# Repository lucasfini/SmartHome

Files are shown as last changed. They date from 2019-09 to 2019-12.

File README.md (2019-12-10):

# MQ-2 (Semiconductor Sensor for Combustible Gas)

## Table of Contents

* [Introduction](#Introduction)
* [Bill of Materials/Budget](#B)
* [Time Commitment](#T)
* [Mechanical Assembly](#M)
* [Pcb Soldering](#P)
* [Power Up](#PU)
* [Unit Testing](#UT)
* [Production Testing](#PT)
* [Reproducible?](#R)

## <a name="Introduction"> Introduction </a>

<p> The MQ-2 is a Metal Oxide Semiconductor that detects LPG, Smoke, Alcohol,Propane, Hydrogen, Methane and Carbon Monoxide. It does this by looking at change of resistence before and after a gas comes in contact with the material. These concentrations can range anywhere from 200 - 10,000ppm. The sensor is great for a multiple range of gas detection, and can be used in a ton of industrial, and at home areas. This Mq-2 sensor from Willwin is a very low-cost, and very responsive sensor. The operating voltage is 5v with it consuming <800mw of energy. It has very easy wiring, and works perfectly with the stm32 blue pill.<p>
 
## UML-Diagram

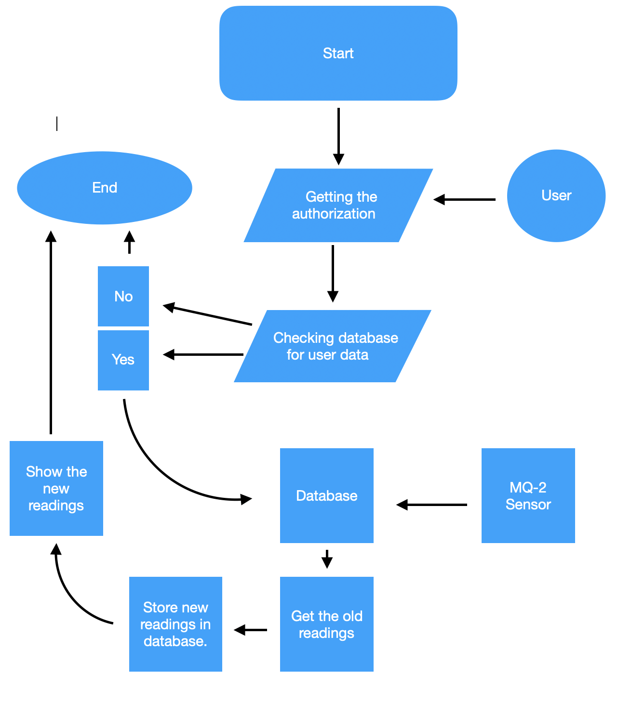
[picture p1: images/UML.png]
image of packages


System Diagram

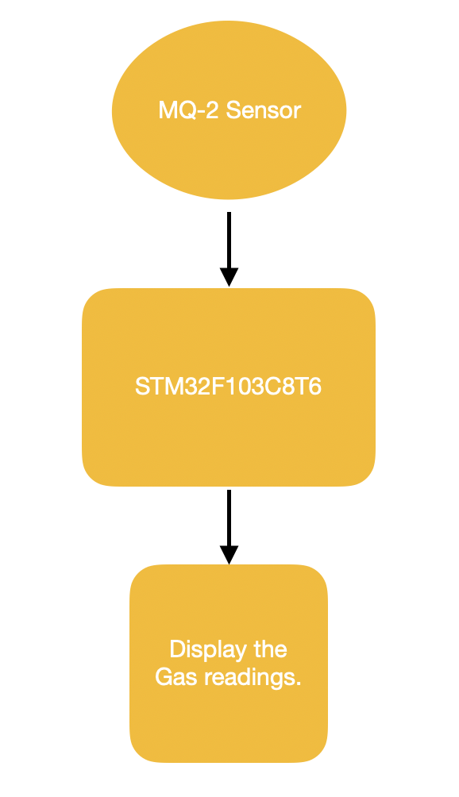
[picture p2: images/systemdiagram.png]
image of packages


## <a name="B"> Bill of Materials/Budget </a>

The required price for my whole project is about $100. This is the price if you are a student at humber, and have collected the parts kit at the beginning of semester 1. If you do not have the parts kit, you will need to pay an extra $120 dollars for the parts kit. I also used the schools prototype lab to get my case and pcb made. If you would like to go to a external dealer, the price will increase on top of the $220 already spent for the parts and the kit. If you are a student the required materials will be below for you to view. 

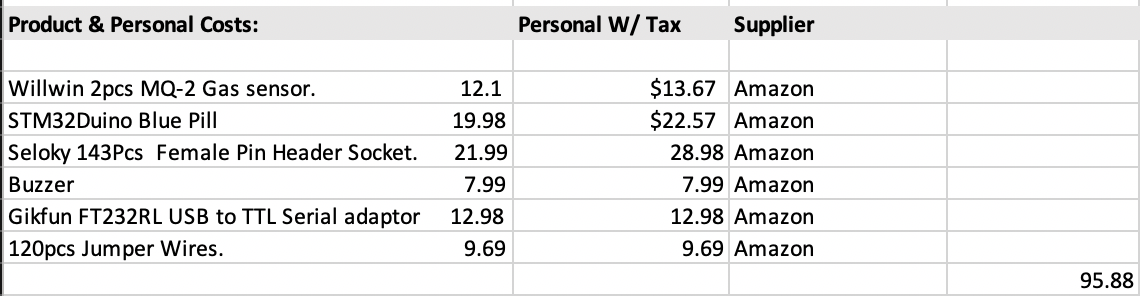
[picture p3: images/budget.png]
image of budget


## <a name="T"> Time Commitment </a>

The first time Commitment I will talk about is the CENG-317 schedule. You will get 14 weeks to complete this hardware assignment. Each week is a new task to do, some will take longer than others. The weeks that most people have difficulties on is week 9 and 11. These weeks are the PCB solder and Enclosure due dates. Since you need external equipment to do these two weeks, it will be more difficult to find the time to do them. Plus, if you design your enclosure or pcb wrong, you will need to keep on trying until you get them right. Note: Try to be ahead for these two weeks, just incase something unexpected happens. 

Now, this is for people that are building this on their free time. If you were to have all the equipment, and just needed to get the pcb and enclosure it should take you about a week, because of the shipping of pcb and enclosure. If you already have a pcb and enclosure you can realistically do this in a weekend. That is only if you have everything with you and are prepared. 

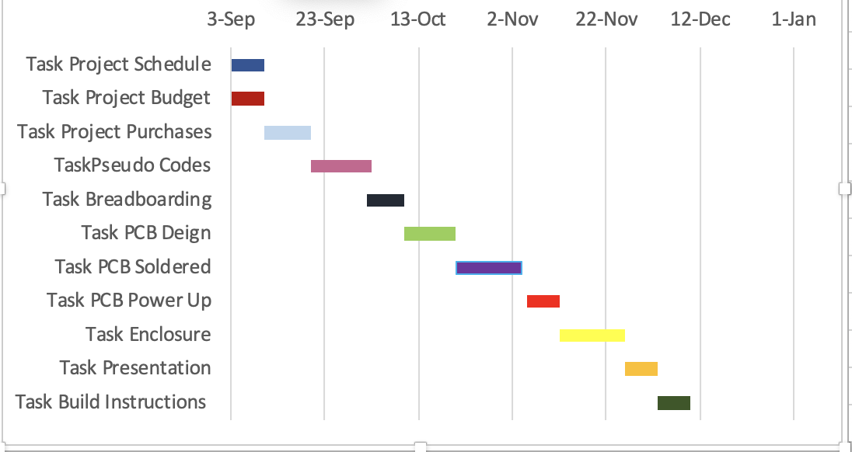
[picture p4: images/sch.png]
image of schedule


## <a name="M"> Mechanical Assembly </a>

Wanna learn how to probably setup,code,wire,and enclose?  **Instructions Below**
Side Note: Before starting please make sure you have the materials listed above, in the budget section. 

1. Install [Arduino](https://www.arduino.cc/en/main/software)
2. To learn how to program the STM32 Bluepill we will start with a simple blink program. First we need to install some board managers. Go to Tools>Boards Manager and install STM32F4xx boards and STM32F1xx/GD32F1xx baords.

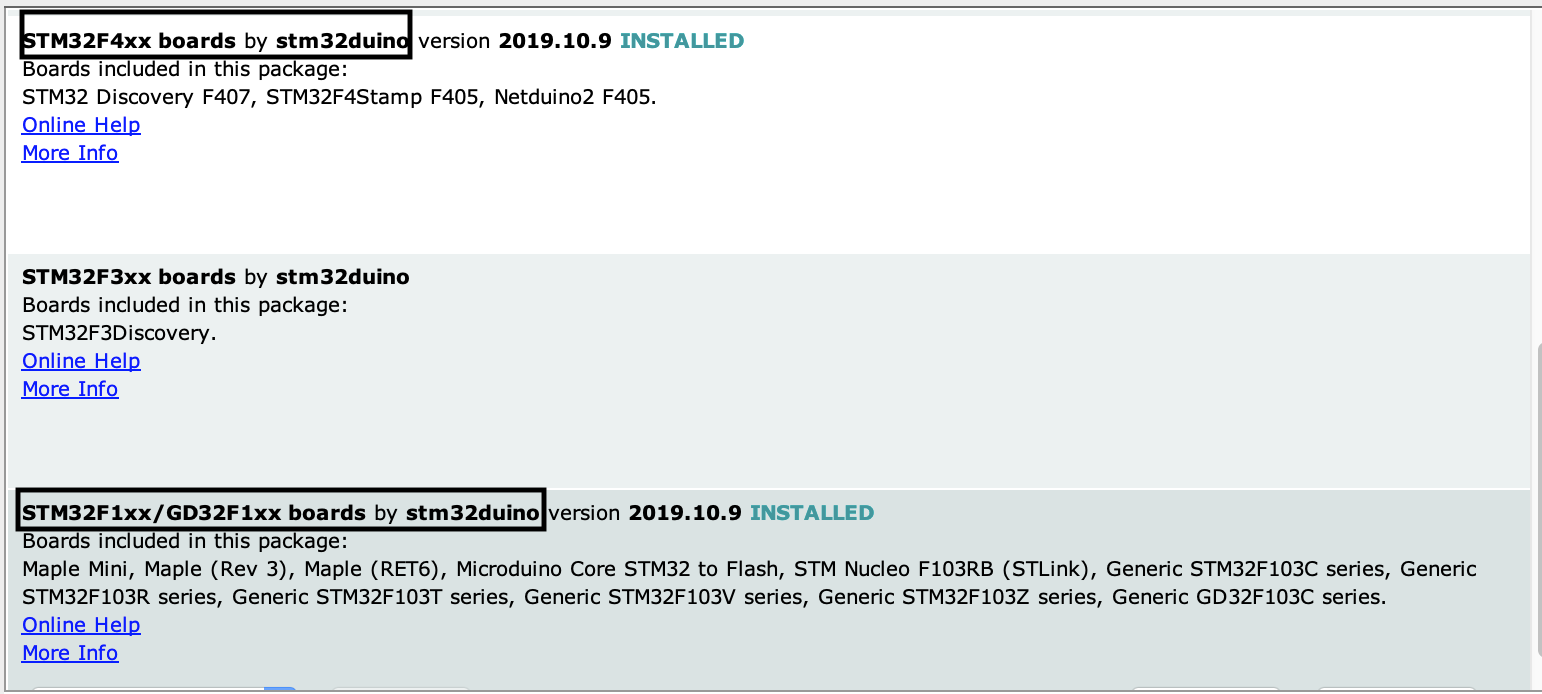
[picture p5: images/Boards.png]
image of baord


3. Next go to Files>Examples>Basics>Blink. Change the code to how it is below.

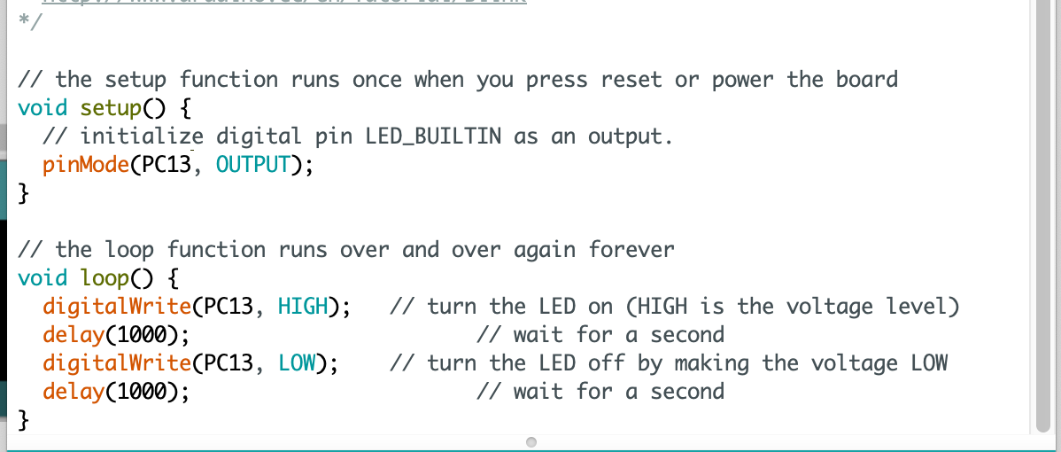
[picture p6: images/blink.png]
image of blinkcode


4.Now you will need to setup the device on your breadboard. Make sure to switch the BOOT0 on the blue pill from 0 to 1. This will put it in programming mode. The picture below will show you how to do it. Once done plug the FTDI programmer into your computer.

Pin Layout:

<p>Programmer to stm32<p>
<p>gnd to G<p>
<p>vcc to 5v<p>
<p>tx to a10<p>
<p>rx to a9<p>

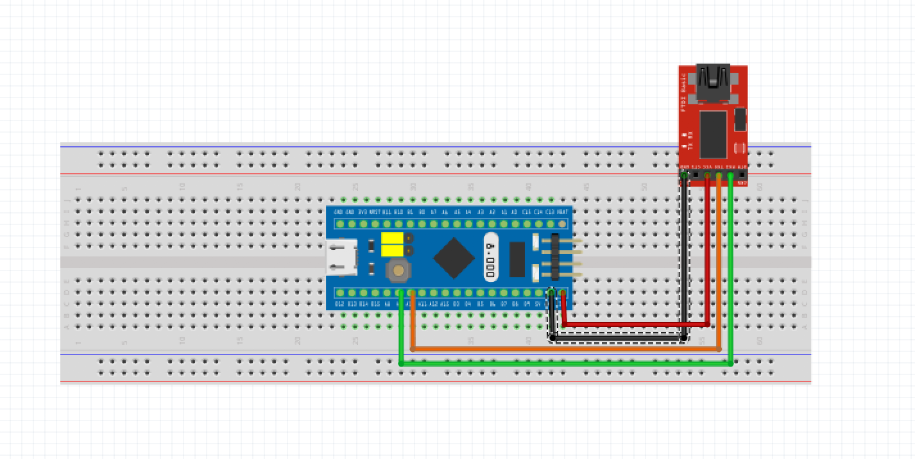
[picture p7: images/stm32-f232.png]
image of breadboard


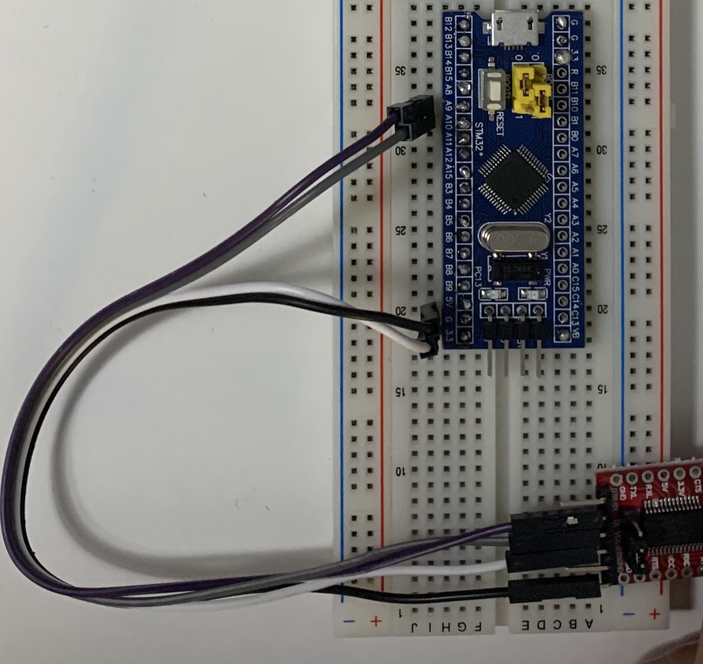
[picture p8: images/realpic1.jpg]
image of breadboard


5. Now go to tools and make sure to have similar options that are in the picture below. 

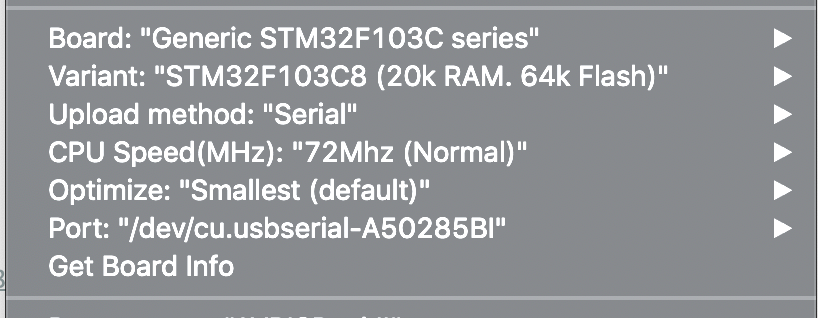
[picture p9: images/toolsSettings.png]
image of breadboard


6. Now once everthing is done, Click upload on the top left of arduino. It should show it compiling and once it is done, there should be a green light that will blink on the STM32. If there is an issue try hitting the reset button on the STM32 and try uploading again. 

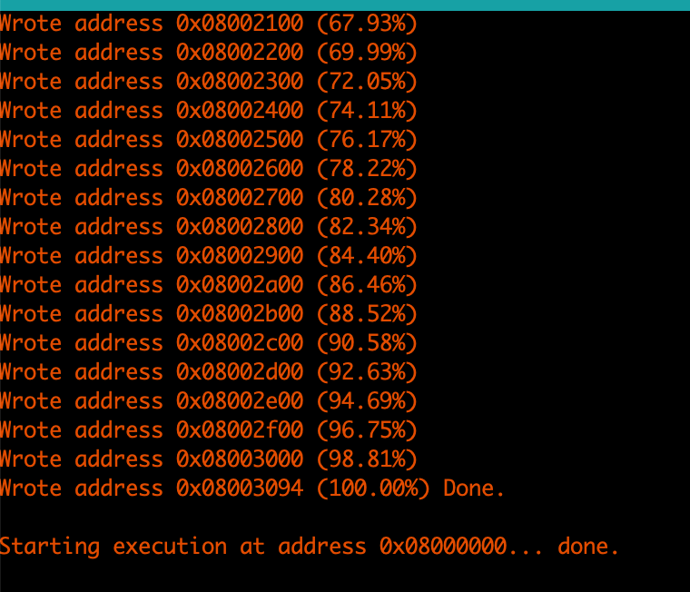
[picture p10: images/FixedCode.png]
image of compile.


7. Now that all that is done with we can continue with attaching the buzzer, and MQ-2 Gas sensor.
The New Connections will be:

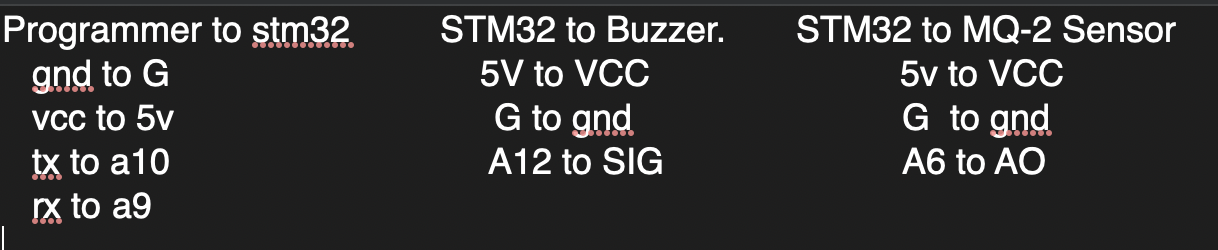
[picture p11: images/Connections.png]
image of completed connections


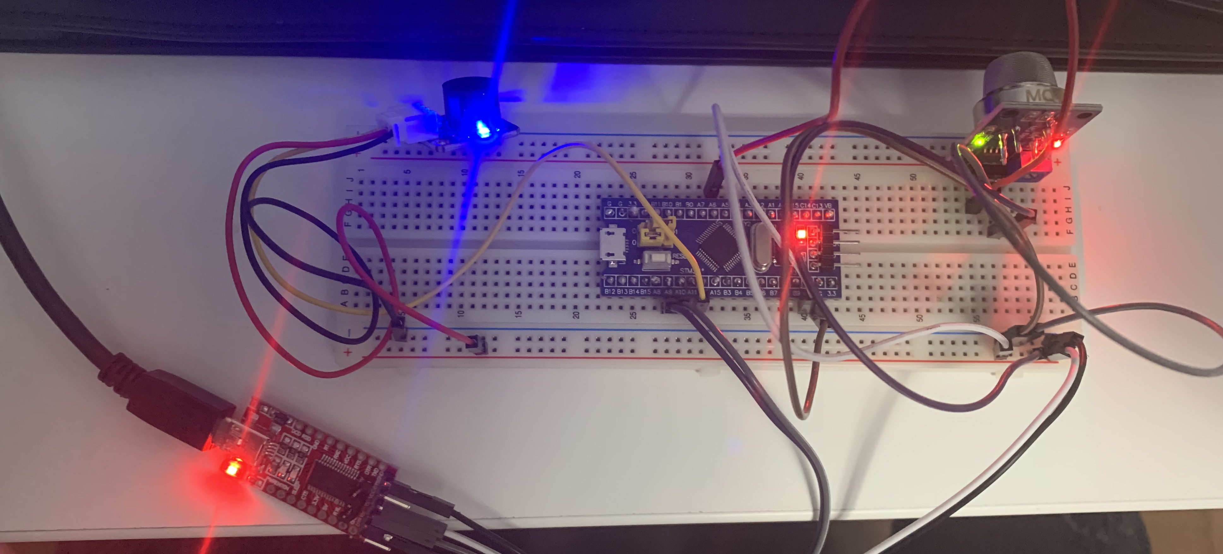
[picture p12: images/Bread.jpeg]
image of completed breadbaord.


## <a name="P"> Pcb and Soldering </a>

Now that we have the breadboarding portion completed, lets move on to PCB completion. I did have some difficulty making the PCB and had to remake my PCB 3 times to get it working perfectly. Note: When imported a part from the internet to fritzing, even though it says it might be the part you need make sure its the right dimentions. This happened to me with my STM32,and I had to remake the PCB board. Another note: If you can't find the right parts online or in their internal library, use a **Generic female Header**. It can be used in place of most parts. After designing the PCB you should send the gerber files to the prototype lab so that they can make your PCB. Takes 1-2 days, depending on time and demand. The solder wasn't to difficult, just make sure you take your time, and make sure no two connections aren't soldered together. 

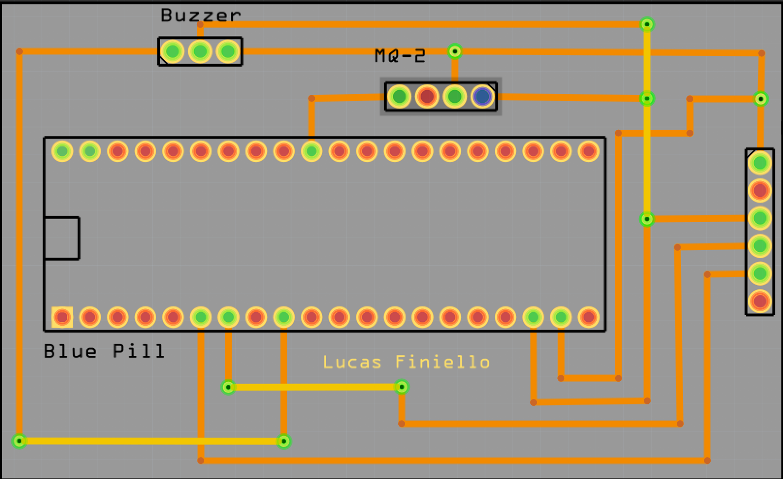
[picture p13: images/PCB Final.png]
Image of Pcb
  
  
 Bottom of the PCB board. I wanted everything on the top, so I made sure to put on the wire on the bottom. Since all the wiring is on the bottom, that means most of the soldering is on the bottom. 
 
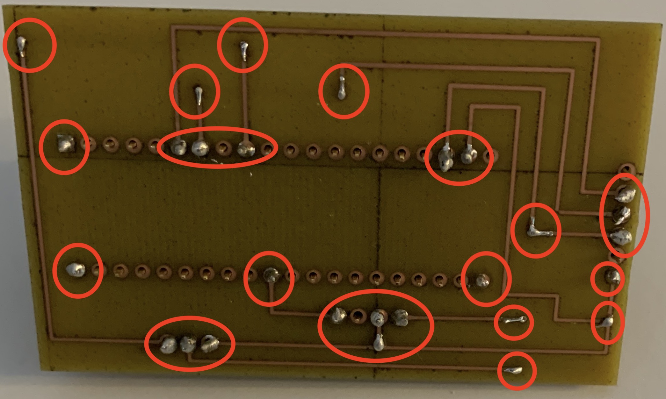
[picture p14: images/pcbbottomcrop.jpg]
Image of Pcb
  
   
 Top of PCB board. This is where my STM32, MQ-2 Sensor, Buzzor and FTDI programmer will plug in. 
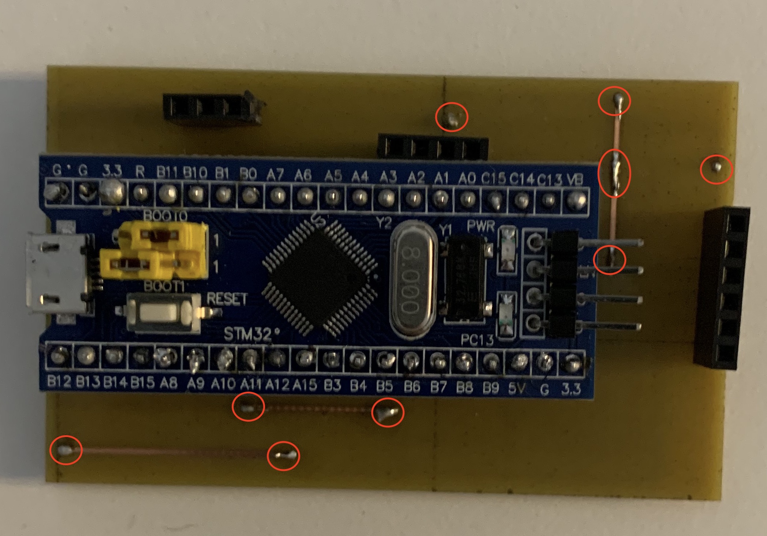
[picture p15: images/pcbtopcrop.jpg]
Image of Pcb
  
      
 How the PCB looks when it is plugged in and all the components are working.
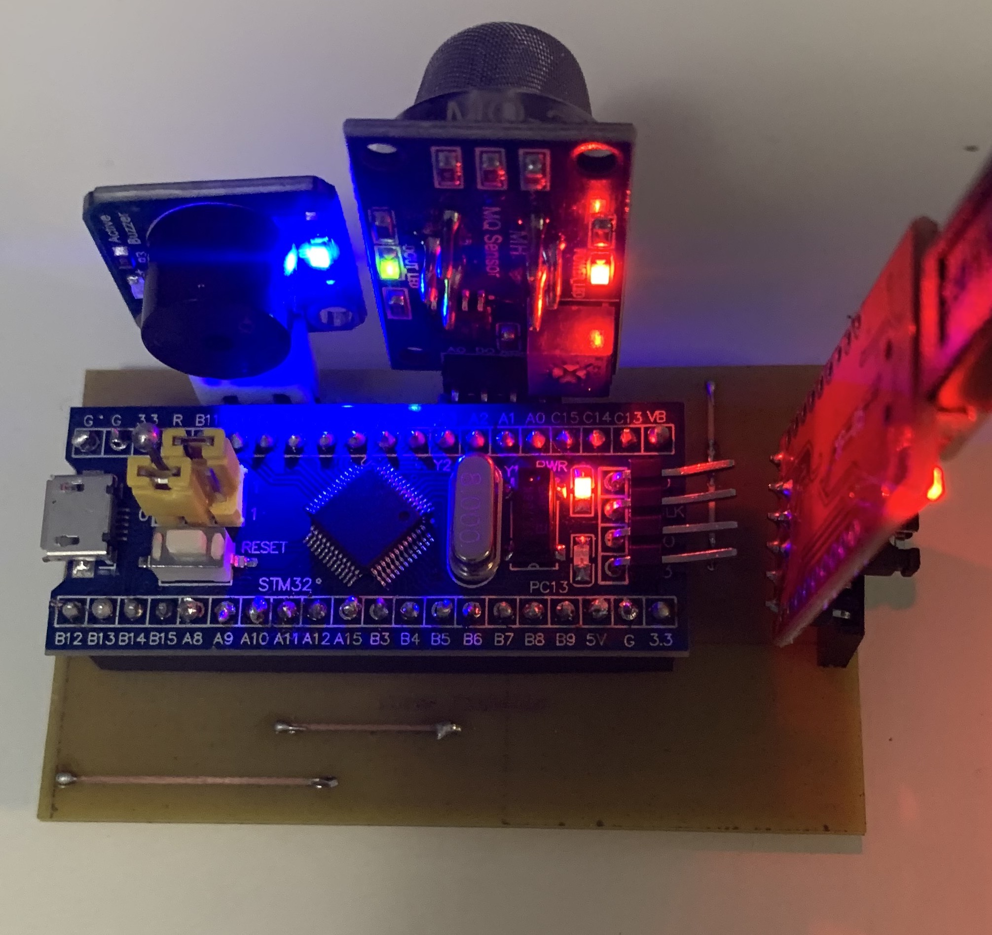
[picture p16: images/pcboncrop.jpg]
Image of Pcb
  

## <a name="PU"> Power Up</a>

Before plugging anything in you want to look at your PCB board and make sure all the wiring goes to the right place, and all the soldering is done correctly. Once plugged in make sure that everything lights up and that nothing is out. If something isn't lit, try fidgeting with the component that isn't turned on. If it still isn't on look at your soldering and make sure all the vias and connections are soldered correctly. If it still isn't working go back to your PCB design and make sure all the connections are correct, and if that doesn't work then you might have a faulty component. 

 How the PCB looks when it is plugged in and all the components are working.
  Image of Pcb

## <a name="UT"> Unit Testing </a>
I tested my product using a lighter. Since lighters contain butane the sensor should be able to sense the gas. As you can see below whenever I activate the lighter, the senser will senses a gas, and once it reaches above a safe thresh hold, the buzzer turns on. Once the thresh hold goes back down below 1100, it is safe and the buzzer turns off. With this sensor you will wanna configure it and make sure it is running properly. You also do need to allow it some time to heat up before use, or else the value might be higher than usual.

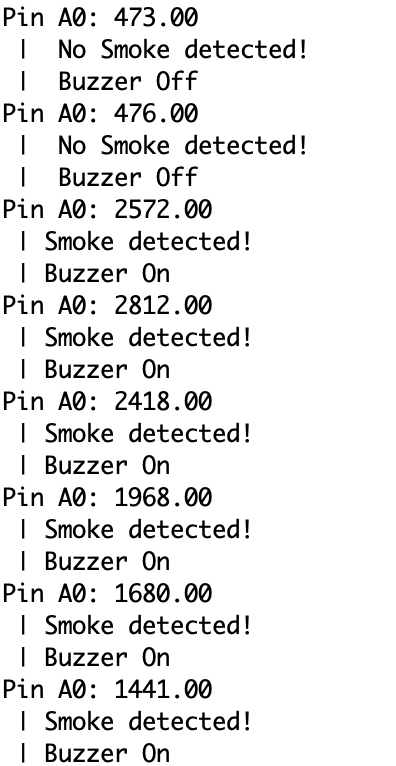
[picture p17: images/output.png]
Image of output

  
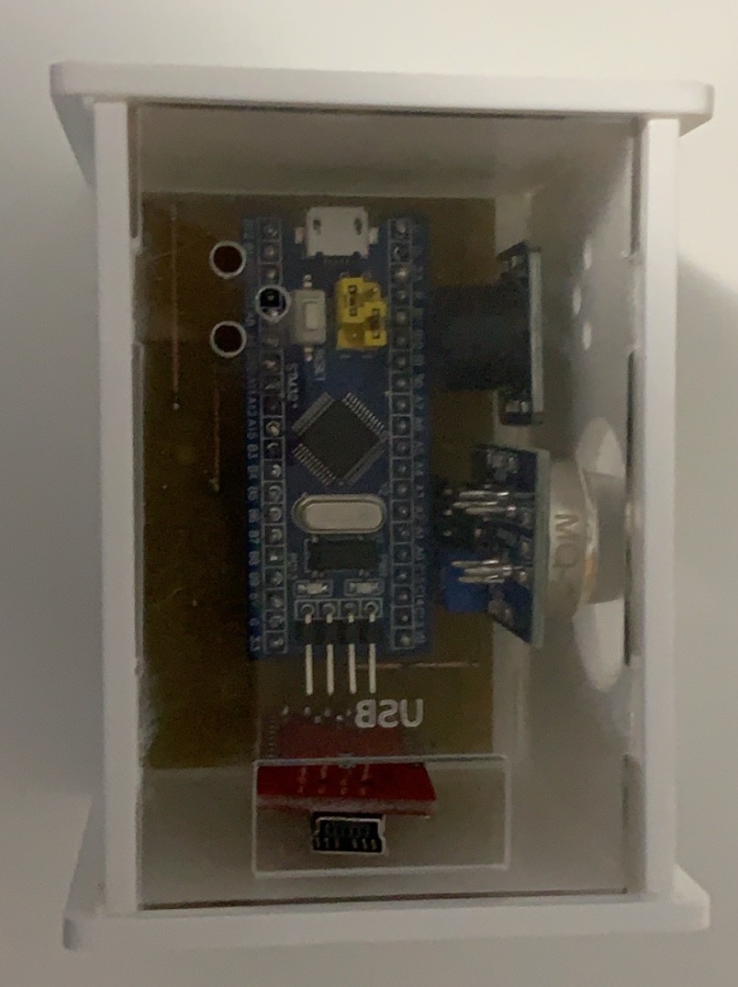
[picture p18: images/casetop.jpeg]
Image of casetop

  
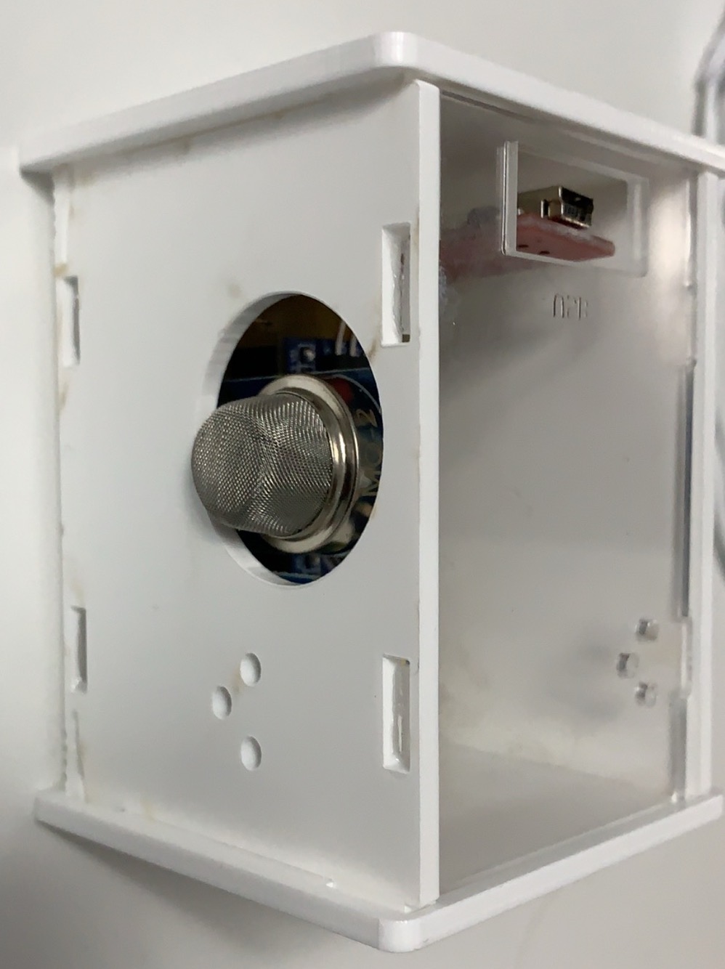
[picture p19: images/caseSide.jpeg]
Image of caseside


## <a name="PT"> Production Testing </a>

With this product I only was able to test one gas, and the only reason for that is because all the other gasses are very dangerous, and hard to get a hold of. I was able to monitor the products data, and make sure everything was running correctly. If I was manufacturing multiple units of this product I would first make sure all soldering was done by automated machinary. It would speed up production time, and efficiency. Secondly, if this is used as a smoke sensor I would hard solder all the components to the PCB. I would do this because it would firstly, be more secure and secondly, users wouldn't have to worry about components coming loose. 

## <a name="R"> Reproducible?  </a>

I believe that by following my instructions the product is reproducible. The only thing I didn't include was the Arduino code for testing out the sensor and that is because I don't want future students fully copying this github.

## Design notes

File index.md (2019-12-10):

 <h1> Smart Home Monitor - Lucas, Andrew, Luca </h1>
 
 <h1 id="november-26th-week-12">November 26th, 2019 (Week 12)</h1>
 
 <p> Finished my powerpoint presentation and my casing. I am all ready to present and have completed everything in the class except the ReadME file.<p>
 
 Image of case top
 
 Image of case side
 
 <h1 id="november-19th-week-11">November 19th, 2019 (Week 11)</h1>
 <p> I have designed the case on coral Draw and plan to lazer cut it. I would like to try to 3d print, but I don't have enough time.<p>
 
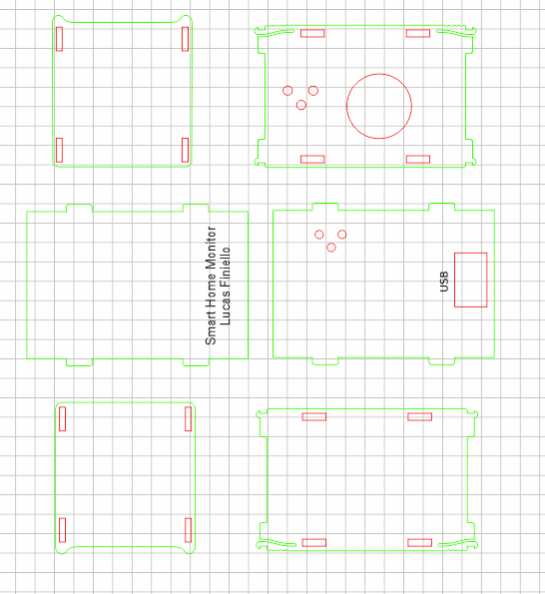
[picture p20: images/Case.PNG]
Image of case
 
 
 <p> I have completed week 9. The PCB is fully operational, and includes everything from week 8
I did have to remake the pcb two times. The first time the file I got online for the blue pill was way to small, so I needed to find another resource.<p>
 
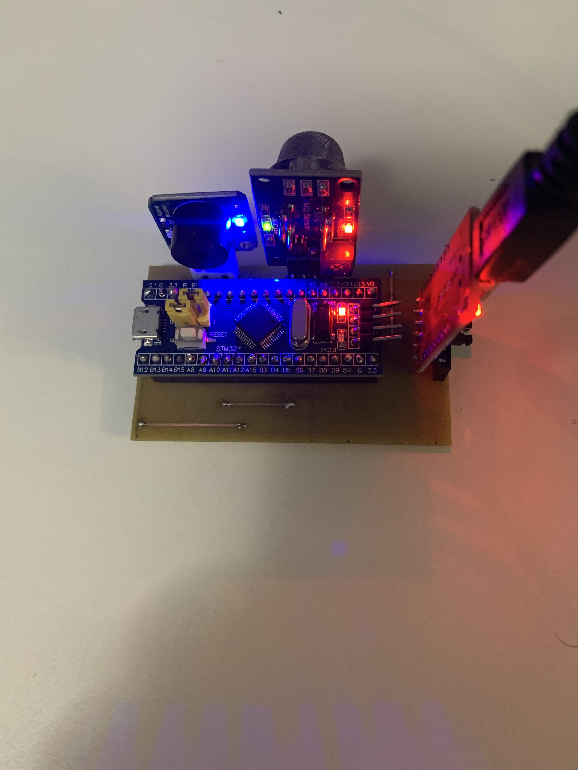
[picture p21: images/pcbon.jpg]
Image of pcbon
 
  
  <p> PCB Bottom <p>
 
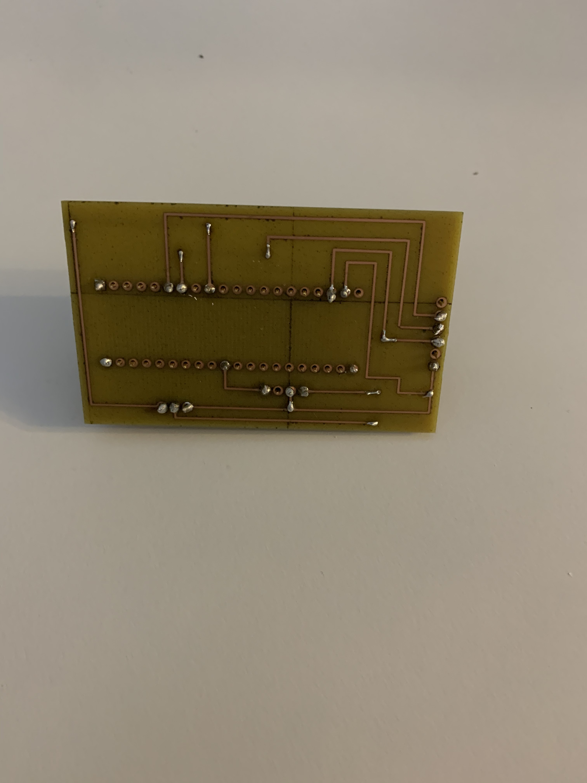
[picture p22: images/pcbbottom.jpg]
Image of pcbbottom
  
   
   <p> PCB Top <p>
 
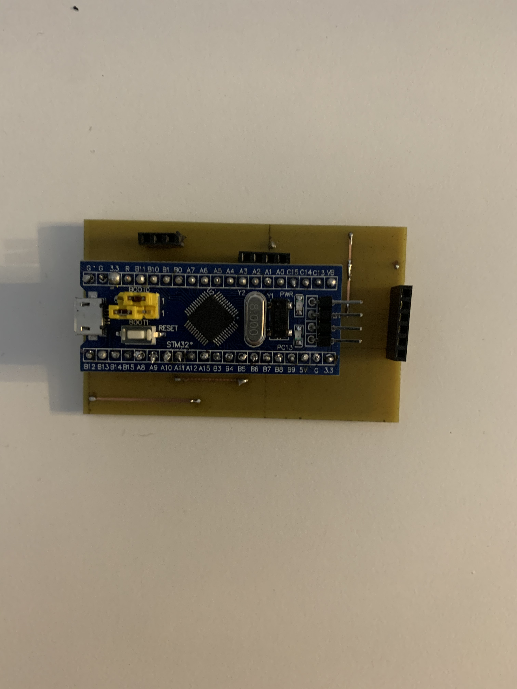
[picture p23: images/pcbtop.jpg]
Image of Pcbtop
  

 <p> I have Completed week 8. I have added a buzzer to the breadboard, and I have added the programmer, and buzzer to the pcb board.<p>
 
  Image of breadboard
  
  Image of output
   
  Image of Pcb

  <h1 id="november-12th-week-10">November 12th, 2019 (Week 10)</h1>
  <p>From using the github page that was supplied by Kristian Medri I was able to fix the errors that were coming up in Arduino 1.8.10. To fix the errors that I was getting you need to download the library down below for the stm32. For Uploading the Blink sketch we have to download the Arduino IDE. Then go to Tools > Boards > Boards Manager, the search the STM32 and install it.<p>
 
 <p> If you need more help with this a good reference that I used is: https://github.com/IshanKhuttan/HumberNavigator <p>
 
  Image of successful message
  
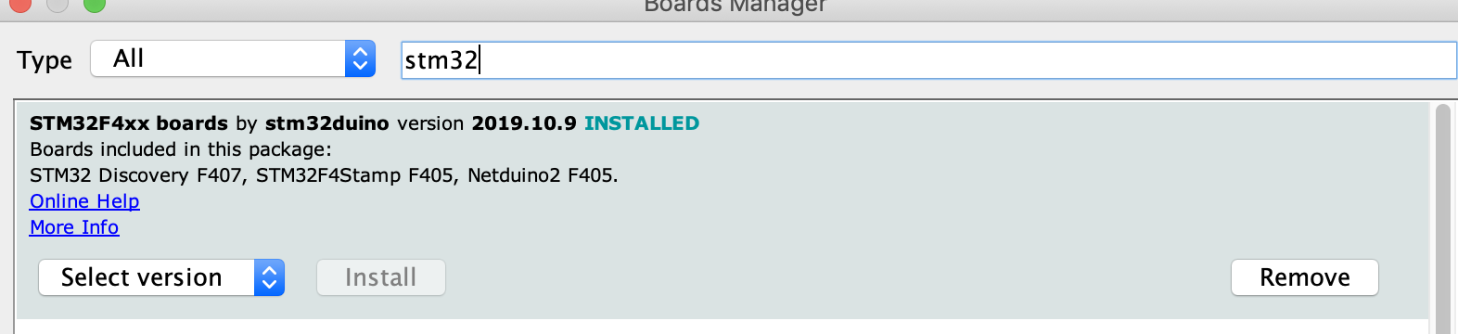
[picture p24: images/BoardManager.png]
Image of board Manager
  
   
  Image of Settings

  <h1 id="november-05th-week-9">November 05th, 2019 (Week 9)</h1>
  <p> Soldering the pcb board was due this week. Was not able to complete on time because of issues with my pcb board. Will try to figure out the problem between stm32 and serial connection. I have listed all the links below of all the videos and websites I visted to try and fix the solution. <p>
 
 [STM32 Arduino (STM32F103C8 / Programming STM32 with Arduino and Mac)](https://www.youtube.com/watch?v=Ze6q6NidS5w)
  [Installing the STM32 USB Bootloader, Easily!](https://www.youtube.com/watch?v=wGbiT6IxGP0&t=176s)
  
  [Getting Started with STM32 using Arduino IDE: Blinking LED](https://circuitdigest.com/microcontroller-projects/getting-started-with-stm32-development-board-stm32f103c8-using-arduino-ide)
  
 [Failed to init Device](https://onstep.groups.io/g/main/topic/failed_to_init_device/25067573?p=Created,,,20,1,0,0)
 
 [Failed to init device STM32 using Arduino](http://stm32duinoforum.com/forum/viewtopic_f_20_t_2569.html)
 
 <p> I have uploaded two pictures of the breadboarding to show how the FT232Rl and Stm32 blue pill are supposed to work together.  <p>
 
 Image of BootLoad Error
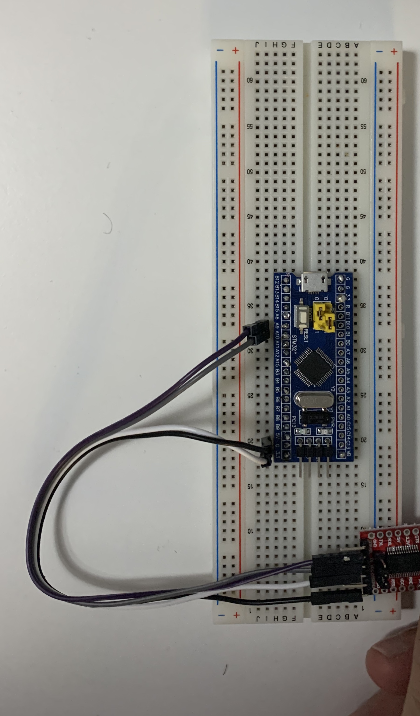
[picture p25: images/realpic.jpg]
Image of BootLoad Error
 

  <h1 id="october-29th-week-8">October 29th, 2019 (Week 8)</h1>
  
  <p> UPDATE-Nov 4: Researched multiple ways to try and come up with a fix for this problem, couldn't figure it out. If serial connection is not successful, will have to use ST-Link v2 instead. <p>
 
 <p> Had problems with the STM32. The error is posted below. <p>
 
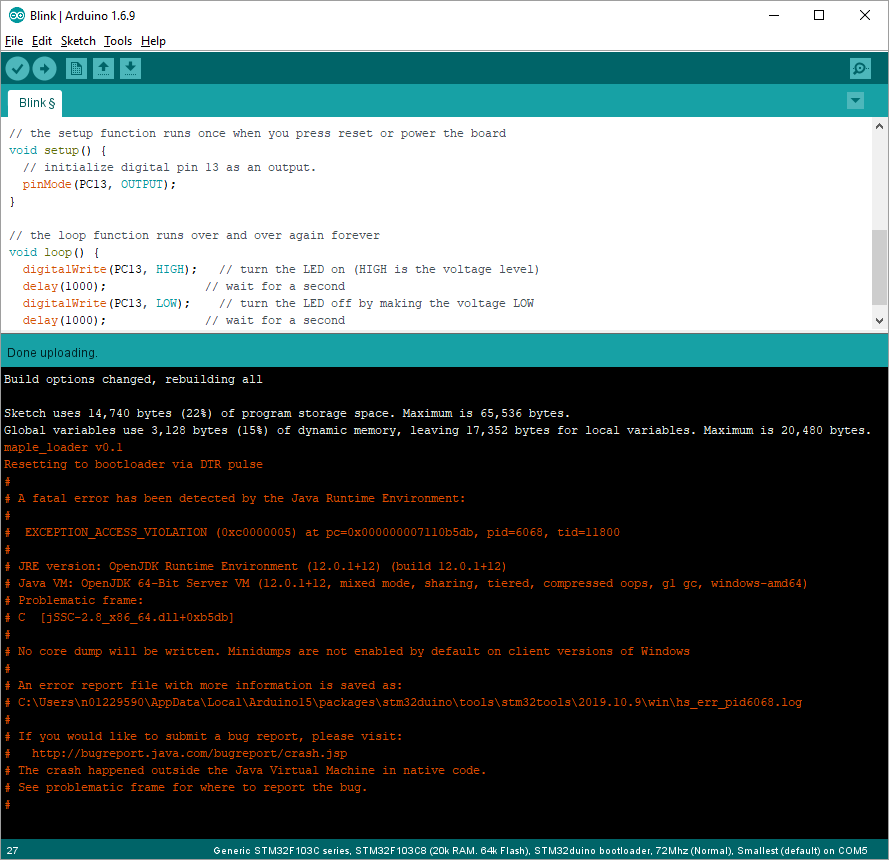
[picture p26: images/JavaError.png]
Image of BootLoad Error
 
 
 <p> I then tried to fix this by ordering a FTDI which would allow the STM32 bootloader to work. Although that also came with errors.
 
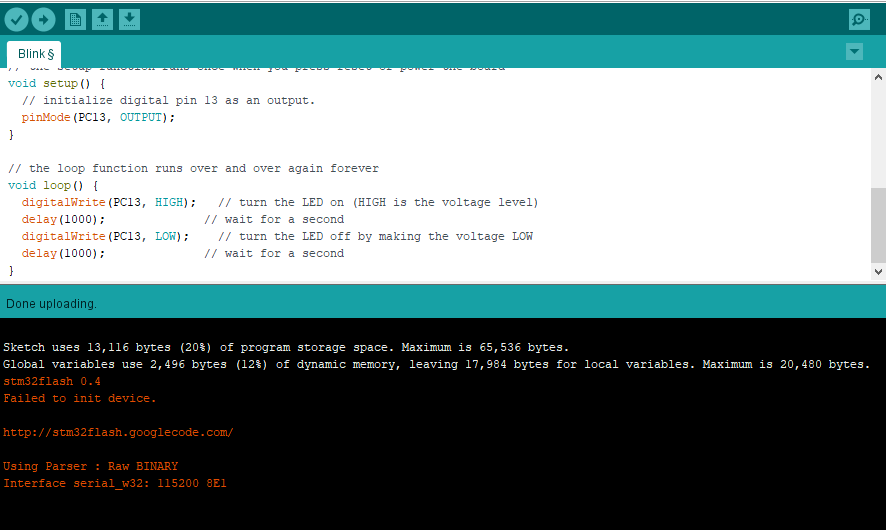
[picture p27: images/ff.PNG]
Image of BootLoad Error
  
 
 <h1 id="october-15th-week-7">October 15th, 2019 (Week 7)</h1>
<p> Finished with the designs for my breadboard, schematic and PCB . Fritzing file is in the electronics Folder. Click on link down below. <p>
 
 [Design Fritzing Link](https://github.com/lucasfini/SmartHome/blob/master/electronics/Ceng318Design.fzz)

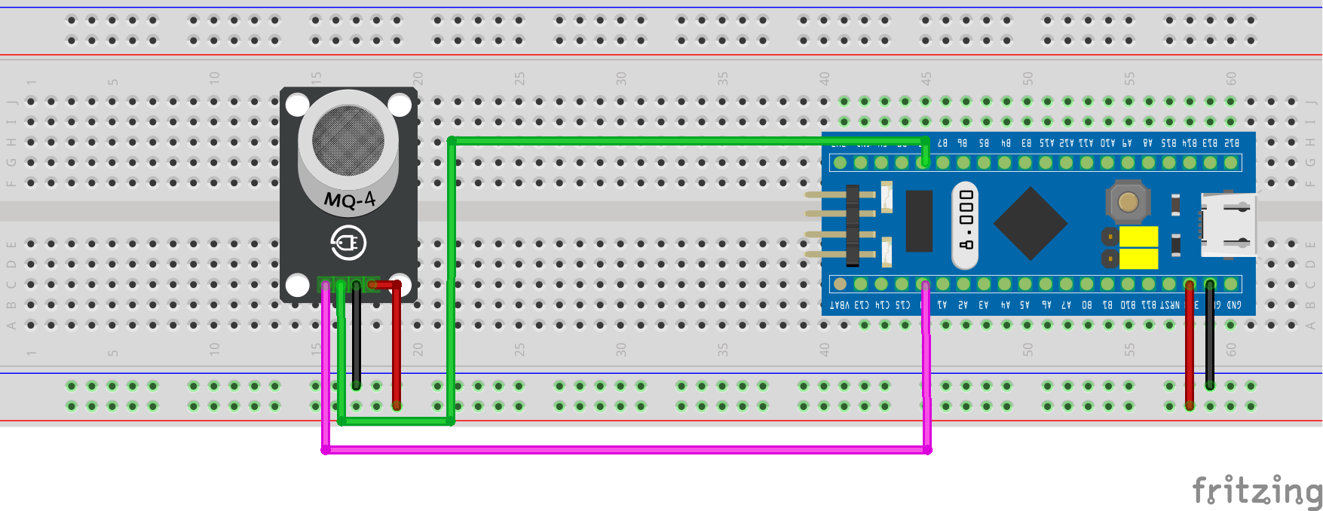
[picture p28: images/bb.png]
Image of breadboard
  
  
  <p> On the sensor, the naming of AO and GND should be switched. I tried to change it in the program but could not figure it out. Since I am using MQ-2 and not MQ-4 the pinouts are a little different. 
  
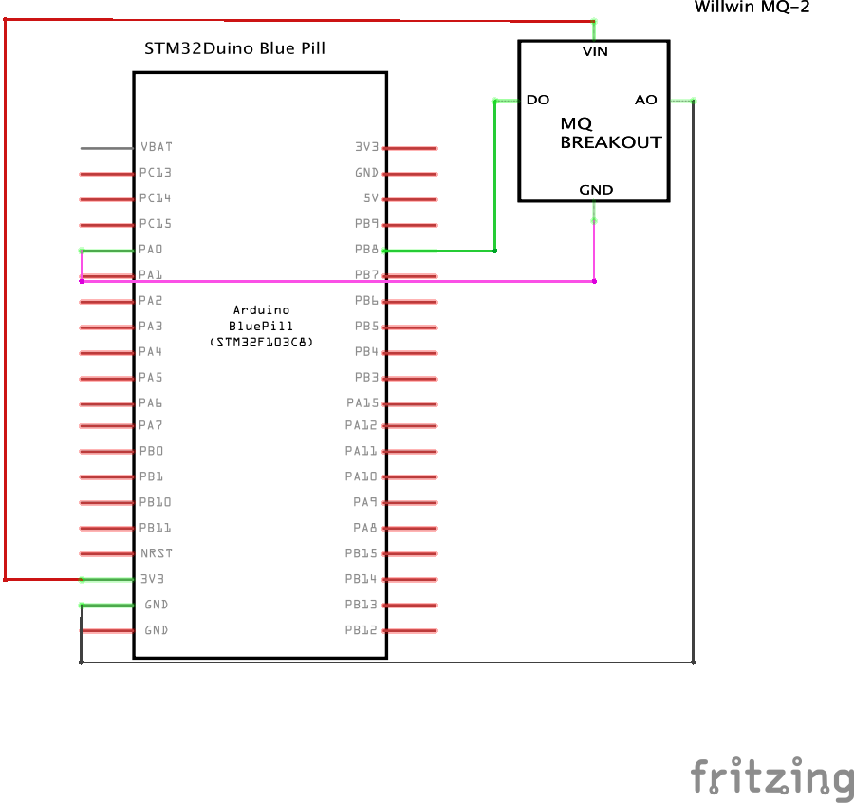
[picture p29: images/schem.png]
Image of Schematic
  
    Image of Pcb

<h1 id="october-08th-week-6">October 08st, 2019 (Week 6)</h1>
<p> Got my parts for future weeks. Getting ready to design the breadboard and pcb <p>
 
 Image of BluePill
 
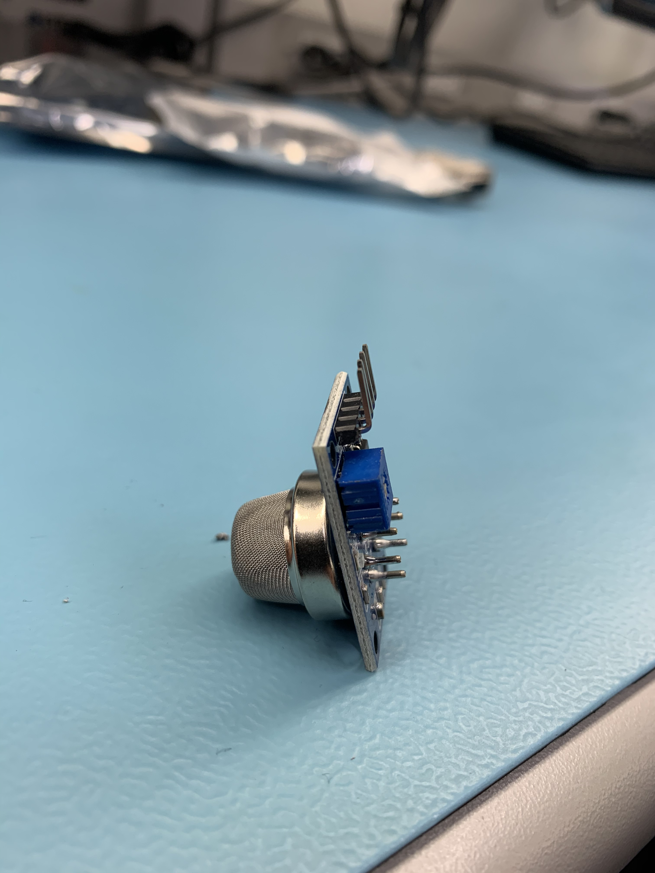
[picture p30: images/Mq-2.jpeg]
Image of Mq-2
 

<h1 id="october-01st-week-5">October 01st, 2019 (Week 5)</h1>
<p> Got my parts for future weeks. Proof of purchase is below. <p>
 
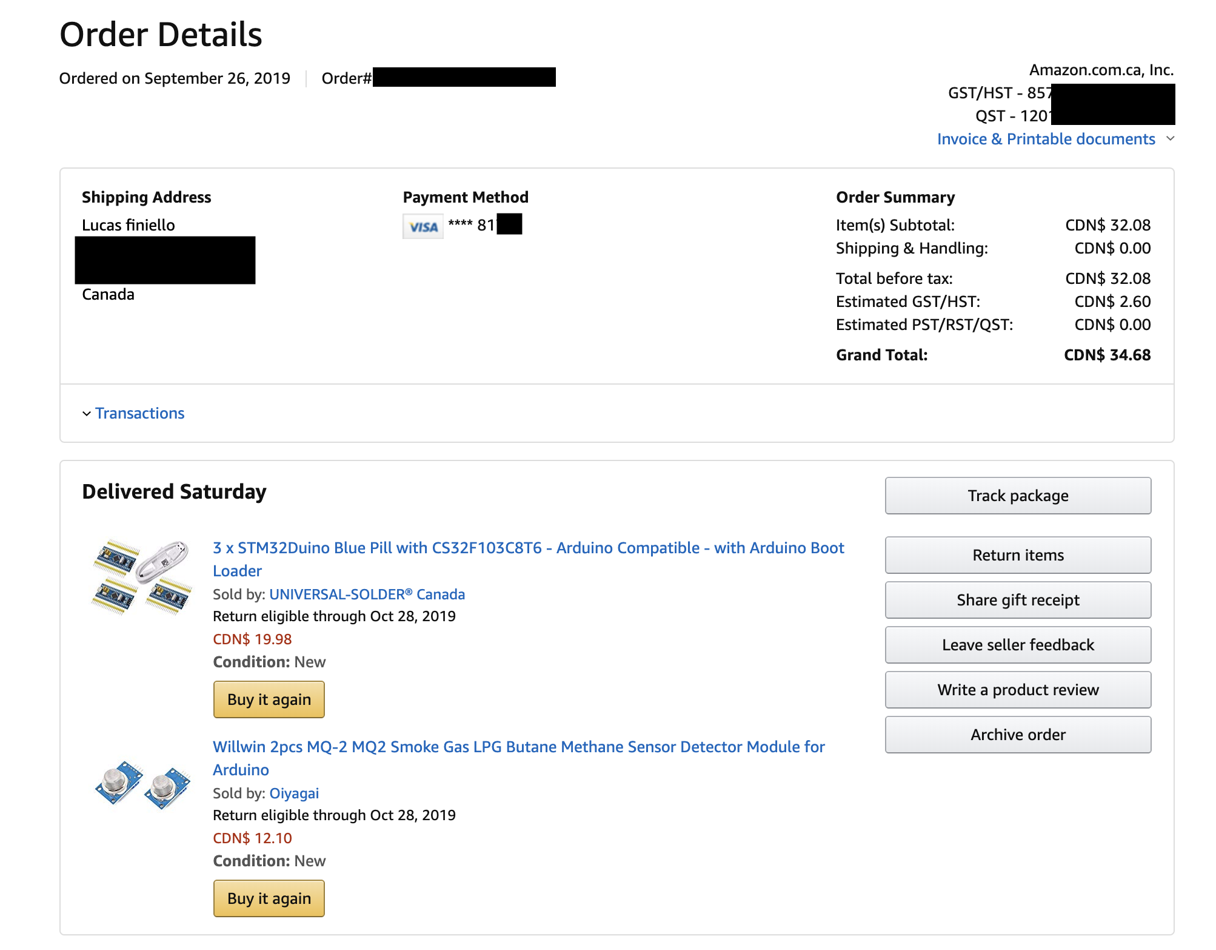
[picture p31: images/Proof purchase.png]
Image of Proof of Purchase
 

 <h1 id="september-24th-week-4">September 24th, 2019 (Week 4)</h1>
<p> Finished with Budget. Need to order Parts for next week. <p>
  
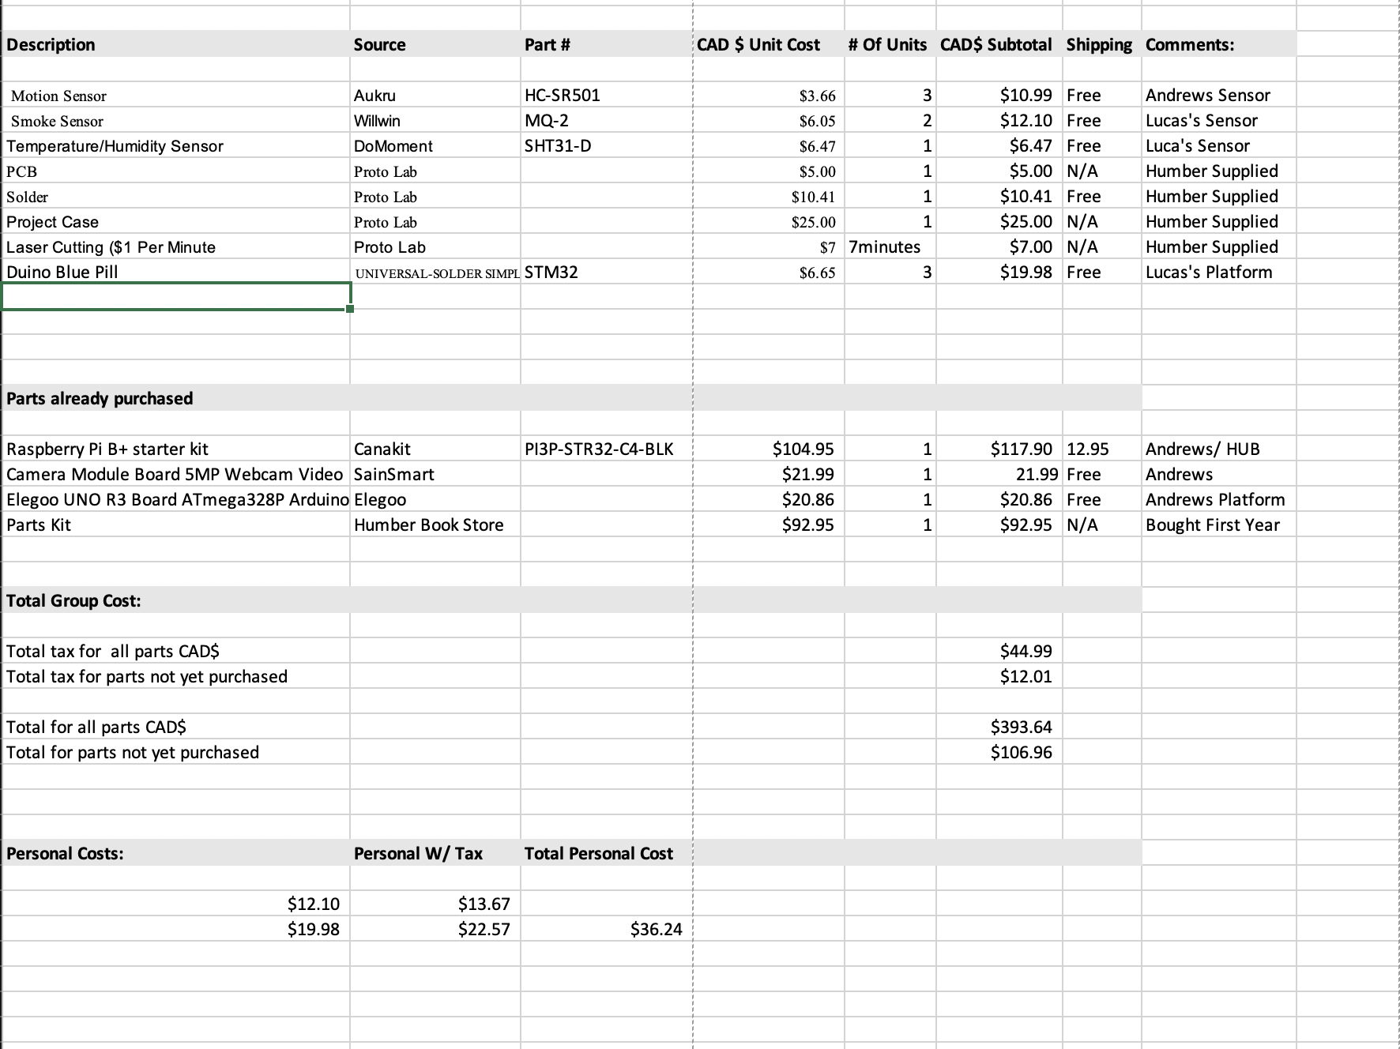
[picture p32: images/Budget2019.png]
Image of Budget
  

<h1 id="september-17th-week-3">September 17th, 2019 (Week 3)</h1>

 <p> Finished with my Schedule, Started to work on my Budget for next week. <p>

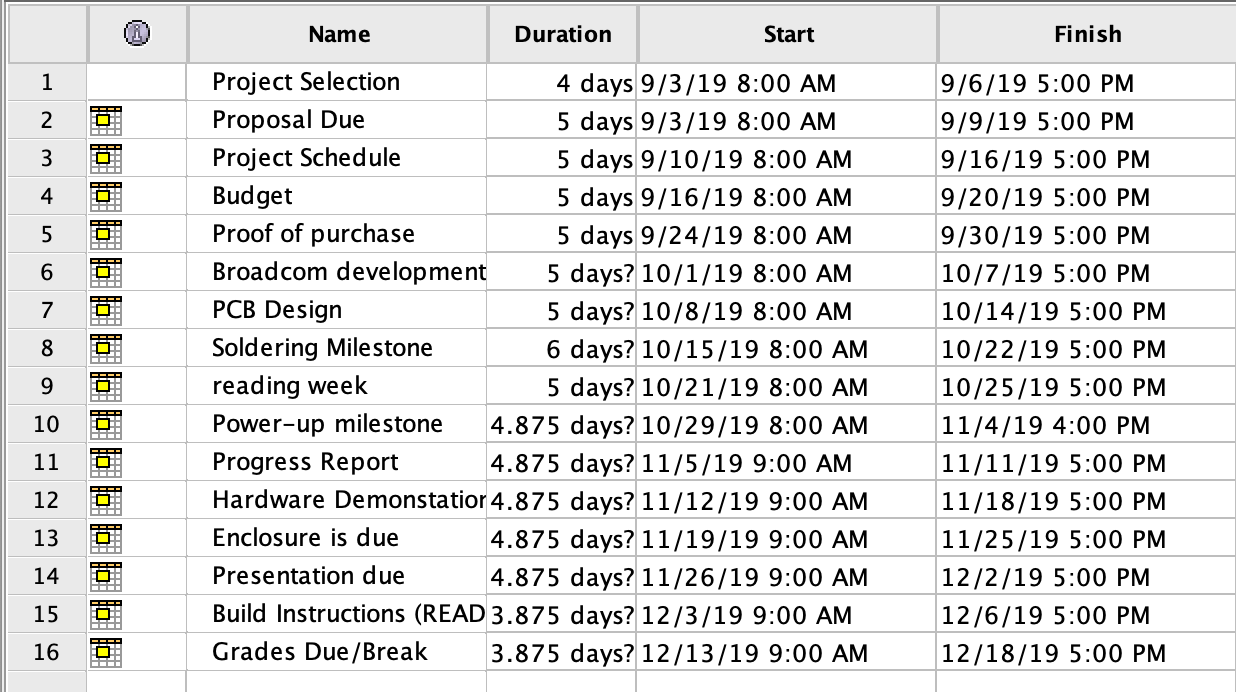
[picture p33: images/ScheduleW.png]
Image of Schedule


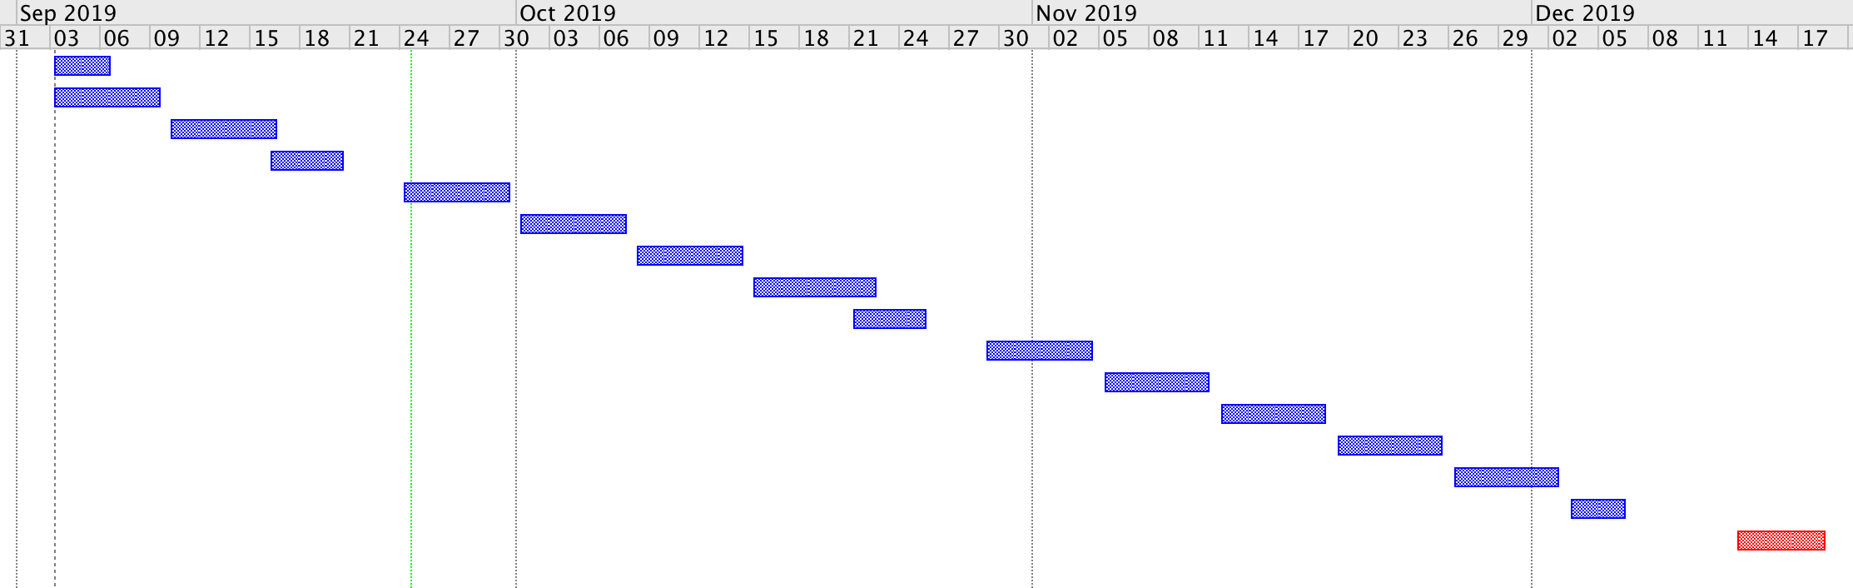
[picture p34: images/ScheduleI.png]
Image of Schedule

 
 <h1 id="september-10th-week-2">September 10th, 2019 (Week 2)</h1>

<p> Today I handed in my proposal. Was not able to complete the whole proposal. Since my group is doing our own project, we are still searching for a collaborator. </p>

[Proposal Link](https://github.com/lucasfini/SmartHome/blob/master/documentation/ProposalContentLucasRev03-1.xlsx)
 
<h1 id="september-5th-week-1">September 5th, 2019 (Week 1)</h1>

<p> Today I created the repository.</p>

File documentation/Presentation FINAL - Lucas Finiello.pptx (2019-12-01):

## MQ-2 Smoke/gas Sensor

Smart Home Monitor – Lucas Finiello

## Introduction

- Smart Home Monitor System ( includes motion detection, temperature/humidity detection and smoke/gas detection)
- Sensor: MQ-2 Smoke/Gas – LPG(liquified petroleum gas), Butane, Methane.
- Development platform used: STM32Duino Blue Pill – with Arduino Boot Loader

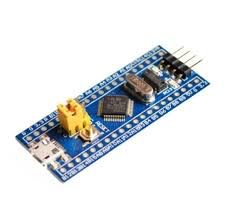
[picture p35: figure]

## Budget

- Initial Buys:
- Willwin 2pcs MQ-2 MQ2 Smoke Gas LPG Butane Methane Sensor Detector Module for Arduino
- STM32Duino Blue Pill with CS32F103C8T6 - Arduino Compatible - with Arduino Boot Loader
- Future Buys:
- Seloky 143Pcs 2.54mm Straight Single Row PCB Board Female Pin Header Socket Connector Strip Assortment Kit for Prototype Shield (4Pin 6Pin 8Pin 10Pin)
- SunFounder Active Buzzer Sensor Module for Arduino and Raspberry Pi
- Gikfun FT232RL 3.3V 5.5V FTDI USB to TTL Serial Adapter Module for Arduino Mini Port (Pack of 2pcs) AE1186x2
- 120pcs Jumper Wires / Dupont Cable 20cm Length

Old

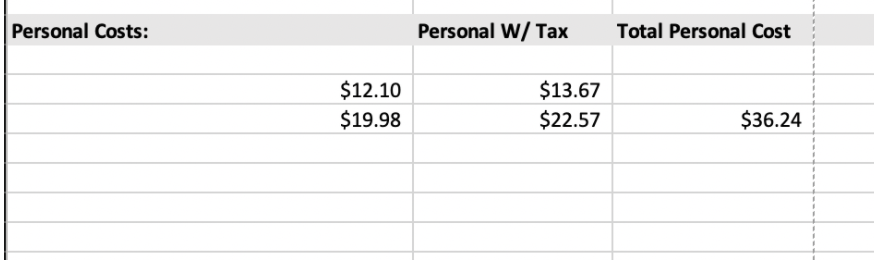
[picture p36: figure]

New

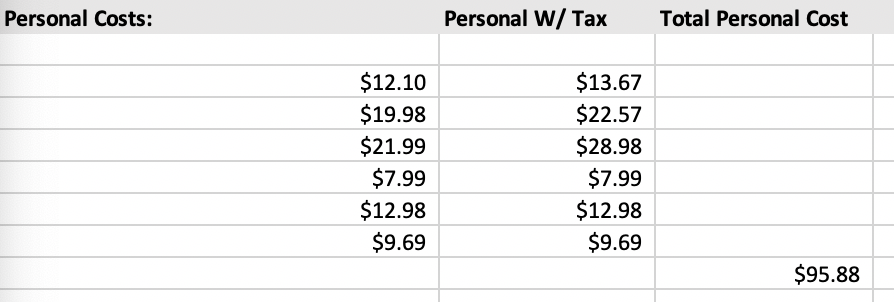
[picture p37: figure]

## Schedule

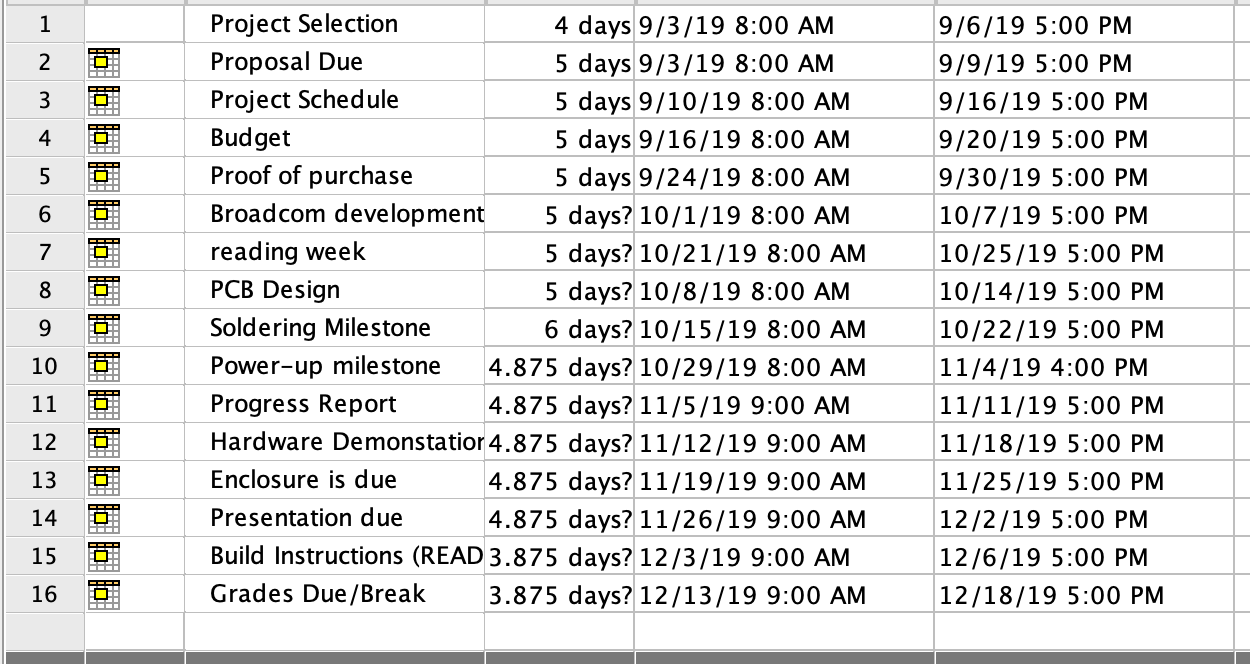
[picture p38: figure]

- Started to fall behind in week 8
-Finished Breadboarding and PCB soldering in week 11.
- Encasing was completed in week 12.

## Images

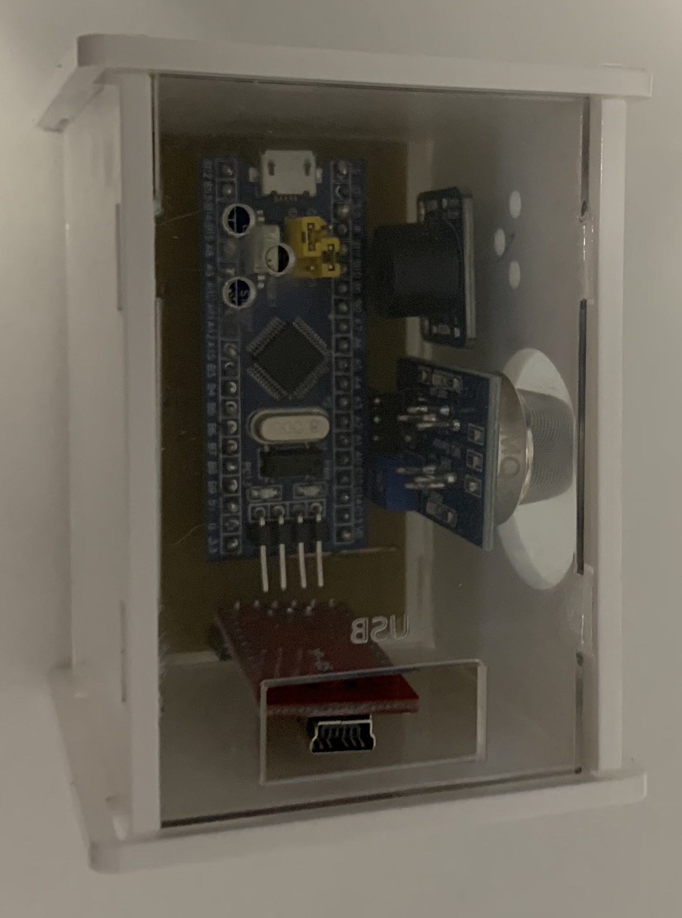
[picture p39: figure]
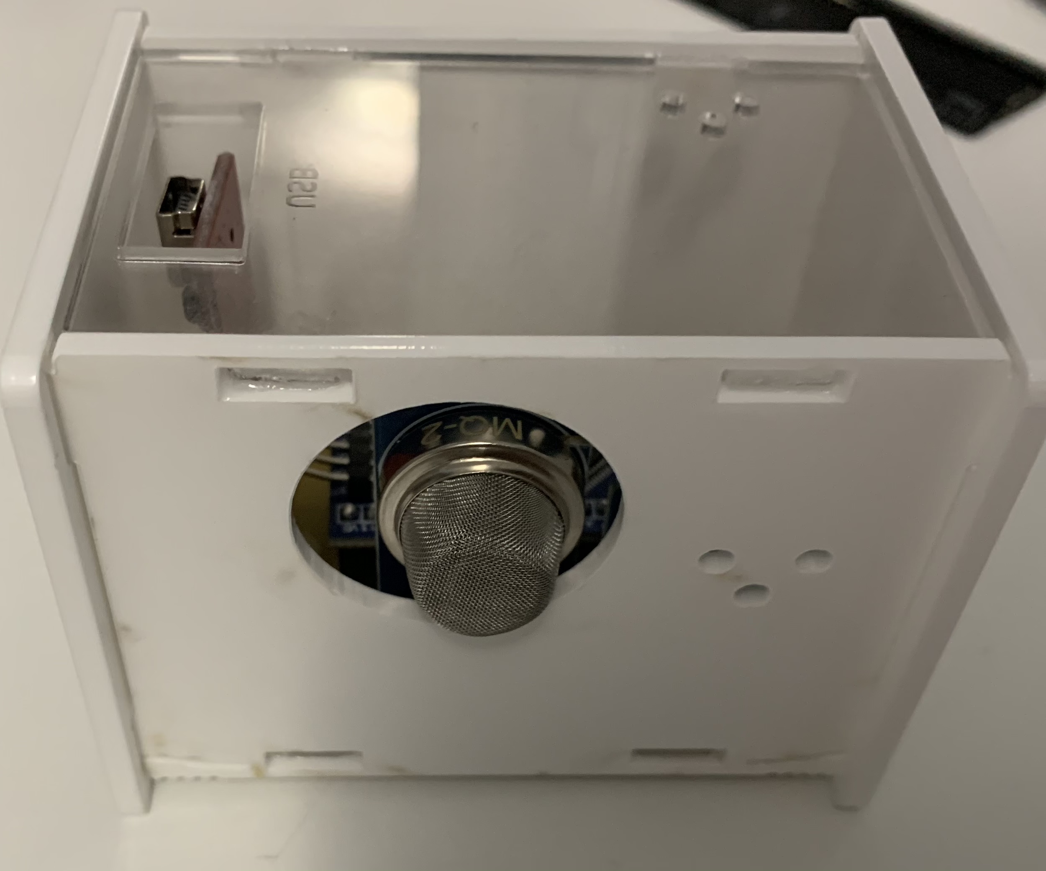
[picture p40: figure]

## Course Knowledge & Outside Knowledge

Course:
- Electric Circuits
- Introduction to Software Engineering
- Embedded Systems
- Technical C
Other:
https://github.com/IshanKhuttan/HumberNavigator
https://www.youtube.com/watch?v=Ze6q6NidS5w

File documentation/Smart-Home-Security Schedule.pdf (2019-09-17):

01

Sep 2019

1 | Project Selection | 4 days | 9/3/19 8:00 AM | 9/6/19 5:00 PM
2 | Proposal Due | 5 days | 9/3/19 8:00 AM | 9/9/19 5:00 PM
3 | Project Schedule | 5 days | 9/10/19 8:00 AM | 9/16/19 5:00 PM
4 | Budget | 5 days | 9/16/19 8:00 AM | 9/20/19 5:00 PM
5 | Proof of purchase | 5 days | 9/24/19 8:00 AM | 9/30/19 5:00 PM
6 | Broadcom developme... | 5 days? | 10/1/19 8:00 AM | 10/7/19 5:00 PM
7 | PCB Design | 5 days? | 10/8/19 8:00 AM | 10/14/19 5:00 PM
8 | Soldering Milestone | 6 days? | 10/15/19 8:00 AM | 10/22/19 5:00 PM
9 | reading week | 5 days? | 10/21/19 8:00 AM | 10/25/19 5:00 PM
10 | Power-up milestone | 4.875 days? | 10/29/19 8:00 AM | 11/4/19 4:00 PM
11 | Progress Report | 4.875 days? | 11/5/19 9:00 AM | 11/11/19 5:00 PM
12 | Hardware Demonstation | 4.875 days? | 11/12/19 9:00 AM | 11/18/19 5:00 PM
13 | Enclosure is due | 4.875 days? | 11/19/19 9:00 AM | 11/25/19 5:00 PM
14 | Presentation due | 4.875 days? | 11/26/19 9:00 AM | 12/2/19 5:00 PM
15 | Build Instructions (REA... 3.875 days? | 12/3/19 9:00 AM | 12/6/19 5:00 PM
16 | Grades Due/Break | 3.875 days? | 12/13/19 9:00 AM | 12/18/19 5:00 PM
Name | Duration | Start | Finish | Predecessors | Resource Names

Smart-Home-Security - page1

25 01

Sep 2019
08 | 15 | 22 | 29 | 06

Oct 2019
13 | 20 | 27 | 03

Nov 2019
10 | 17 | 24 | 01

Dec 2019
08 | 15 | 22 | 29 | 05

Jan 2020
12

Smart-Home-Security - page2

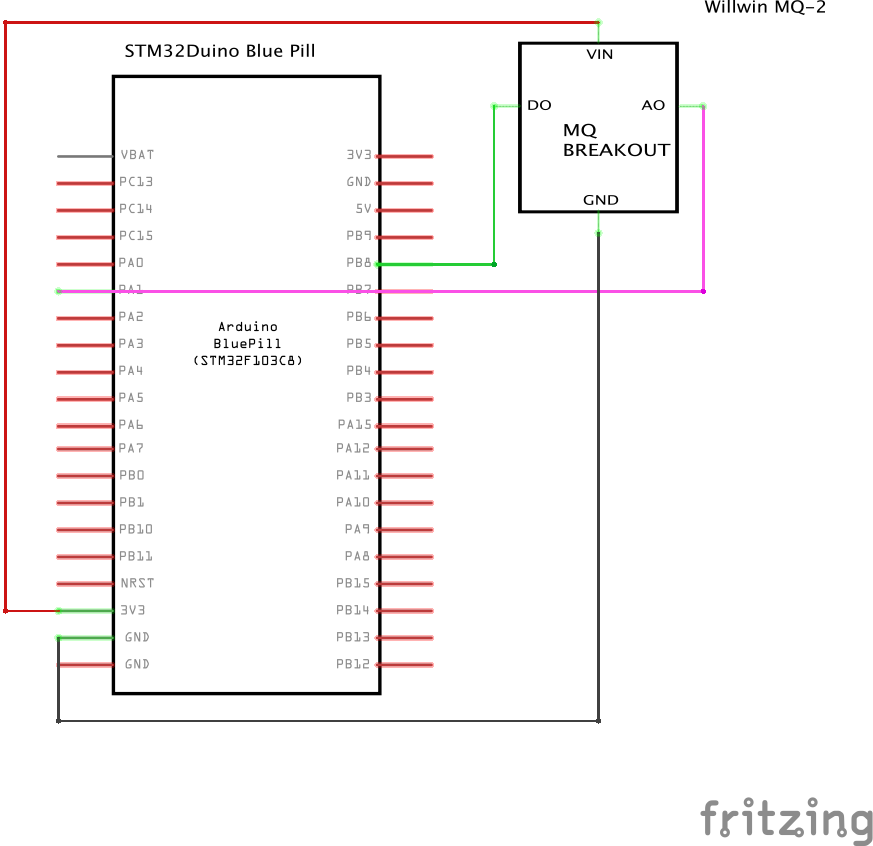
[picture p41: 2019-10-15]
images/Schematic1.png

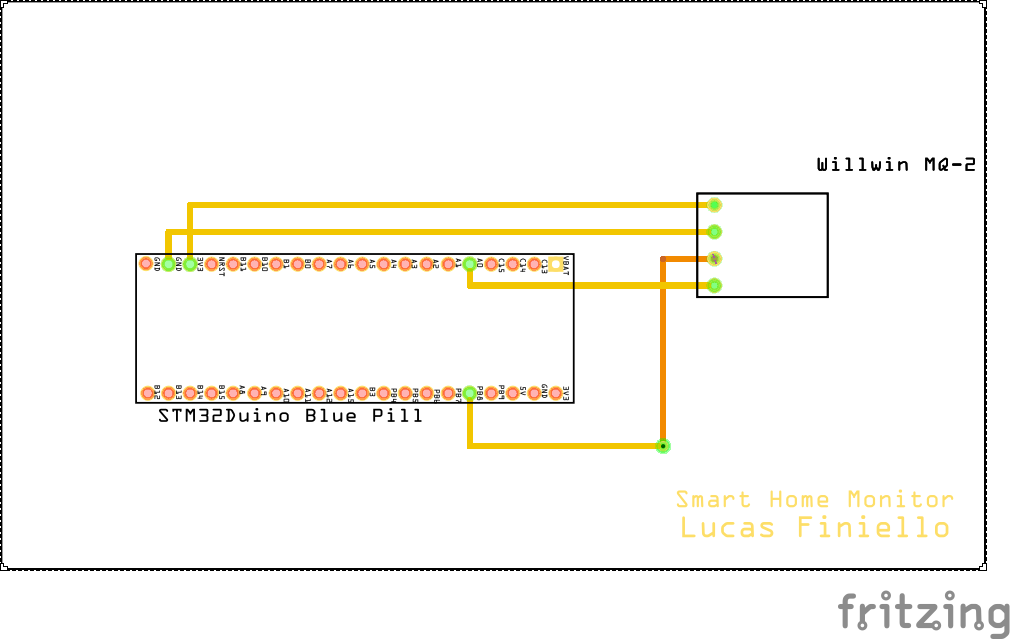
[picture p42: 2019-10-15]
images/Pcb2.png

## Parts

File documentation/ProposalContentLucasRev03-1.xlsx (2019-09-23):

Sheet: DataEntry
Submission Date | 2019-09-10
Project Name | Smart Home Monitor
Student Names | Lucas Finiello, Andrew Liauba, Luca Rojas
Project repository | https://github.com/lucasfini/Smart-Home
SensorsEffectors choices | temperature/humity sensor, Smoke sensor(MQ-2), Motion sensor(HC-SR501), Camera, Mircrophone sensor
The database will store | Profiles, videos, pictures, ids
The mobile device functionality will include | The mobile devices functionality will include : sensor notification, secure/unsecure device, look at data
I will be collaborating with the following company/department | Talked to Austin Tian, he put us in contact with professor khan, who will be our collaborator.
My group in the winter semester will include | lucas Finiello, Andrew Liauba, Luca Rojas
50 word problem statement | When leaving home, we want it to be safe and secure. Safe from criminals, but also from other dangerous realities. This is why our Monitor will include a temperture/humidity sensor a smoke sensor and a Motion sensor. With these sensors, it will make the home much more safe and secure.
100 words of background | The Smart Home Monitor we are creating will include a bunch of functions that will be kept beside the front door of any home. The motion sensor will allow the home owner to be notified whenever somone enters and exits the home through the front door. With this we will include a camera and speaker to capture a photo of the criminal and scare them away from pushing further into the home. The temperature/humity sensor will allow the home owner to always know what the inside temperature of the home is. It is also a safety feature because if the sensor reads the temperature too high it will notify the home owner. Since hydrogen, and butane gas are colorless and odourless, it can be very dangerous if there is a leak. With the smoke sensor included in the Smart Home monitor, it will notify the home owner who can safely notify the authorities.
Current product APA citation | Colon, A., Griffith, E., Colon, A., Griffith, E., Eric, & Ziff-Davis. (2019, August 27). The Best Smart Home Devices for 2019. Retrieved from https://www.pcmag.com/article/303814/the-best-smart-home-devices-for-2019
Existing research IEEE paper APA citation | **Work in Progress**
Brief description of planned purchases | HC-SR501 Motion Sensor MQ-2 Smoke Sensor Rasberry PI B+ DHT11-Temperature/Humidity Sensor Camera, Speaker
Solution description | With this Smart Home monitor, it will allow the home owner to feel much safer with extra security. It will not include a screen and will work with the users phone to interact with the device. This will be done over bluetooth or wifi.

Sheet: DataBase
Submission Date | Project Name | Student Names | Project repository | SensorsEffectors choices | The database will store | The mobile device functionality will include | I will be collaborating with the following company/department | My group in the winter semester will include | 50 word problem statement | 100 words of background | Current product APA citation | Existing research IEEE paper APA citation | Brief description of planned purchases | Solution description
43718 | Smart Home Monitor | Lucas Finiello, Andrew Liauba, Luca Rojas | https://github.com/lucasfini/Smart-Home | temperature/humity sensor, Smoke sensor(MQ-2), Motion sensor(HC-SR501), Camera, Mircrophone sensor | Profiles, videos, pictures, ids | The mobile devices functionality will include : sensor notification, secure/unsecure device, look at data | Talked to Austin Tian, he put us in contact with professor khan, who will be our collaborator. | lucas Finiello, Andrew Liauba, Luca Rojas | When leaving home, we want it to be safe and secure. Safe from criminals, but also from other dangerous realities. This is why our Monitor will include a temperture/humidity sensor a smoke sensor and a Motion sensor. With these sensors, it will make the home much more safe and secure. | The Smart Home Monitor we are creating will include a bunch of functions that will be kept beside the front door of any home. The motion sensor will allow the home owner to be notified whenever somone enters and exits the home through the front door. With this we will include a camera and speaker to capture a photo of the criminal and scare them away from pushing further into the home. The temperature/humity sensor will allow the home owner to always know what the inside temperature of the home is. It is also a safety feature because if the sensor reads the temperature too high it will notify the home owner. Since hydrogen, and butane gas are colorless and odourless, it can be very dangerous if there is a leak. With the smoke sensor included in the Smart Home monitor, it will notify the home owner who can safely notify the authorities. | Colon, A., Griffith, E., Colon, A., Griffith, E., Eric, & Ziff-Davis. (2019, August 27). The Best Smart Home Devices for 2019. Retrieved from https://www.pcmag.com/article/303814/the-best-smart-home-devices-for-2019 | **Work in Progress** | HC-SR501 Motion Sensor MQ-2 Smoke Sensor Rasberry PI B+ DHT11-Temperature/Humidity Sensor Camera, Speaker | #REF!

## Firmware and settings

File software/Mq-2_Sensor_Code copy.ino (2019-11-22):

#include <Arduino.h>


#define smokeA0 (PA6)
#define buzzer (PA12)
int sensorThres = 1100;

#define LED PC13
void setup() {
  // put your setup code here, to run once:

pinMode(smokeA0,INPUT);
pinMode(LED,OUTPUT);
 pinMode(buzzer, OUTPUT);
Serial.begin(9600);
 Serial.println("Gas sensor warming up!");
 delay(20000); // allow the MQ-2 to warm up


}

void loop() {
  float analogSensor = analogRead(smokeA0);
  Serial.print("Pin A0: ");
  Serial.println(analogSensor);
 

  if(analogSensor > sensorThres)
  {
    digitalWrite(LED,LOW);
    Serial.println(" | Smoke detected!");
    Serial.println(" | Buzzer On");
    tone(buzzer, 1000, 200);
    delay(100);
    noTone(buzzer);
  }
  else
  {
    digitalWrite(LED,HIGH);
    Serial.println(" |  No Smoke detected!");
    Serial.println(" |  Buzzer Off");
    noTone(buzzer);

  }
    delay(1000);
}

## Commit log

2019-09-10 *work in progress*
    [ProposalContentLucasRev03.xlsx]
2019-11-22 Add files via upload
    BreadBoard Design
    [Ceng318Design2.fzz]
